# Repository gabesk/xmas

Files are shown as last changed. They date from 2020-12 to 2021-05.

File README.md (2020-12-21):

# xmas
# xmascard
Merry Christmas!

Welcome to the Electronic Christmas Tree Christmas Card. As you no doubt figured out already, to get started just push the button and enjoy the light show.

Additionally, this board is intended to be at least somewhat more than just an amusement; you can do things with it, and the entire schematic and program are open source on GitHub for you to see.

It’s powered by a Lattice FPGA, and you can add new patterns by plugging the USB connector in to the computer.

Unfortunately, I haven't gotten a chance to document this yet; I'll try to do so by Christmas itself. In the meantime, you can poke at the source code and try the instructions below, but I'm not sure they are actually correct. :(

## Interacting with the board

Double click the `light_control.py` file on your computer. It should open a window. Click **Connect**, and follow the instructions. It will ask you to plug in the Christmas Tree board, and if all goes well, it will print that it was successfully connected in the bottom of the window.

Now that you're connected, click any of the lights on the tree. They should change on the board, too! :)

## Creating your own patterns
What else can you do? Well, you can make your own patterns, using the `convert_animation_file.py` and `upload_new_pattern.py` programs.

These programs accept text files containing animations patterns and downloads them to the board for display.

The animation files work like so:

Each step in the animation is specified on a line. Each line specifies the brightness of the LEDs, from the top left to the bottom right. Each LED is two digits from 0 to 7 for the red, then green brightness. The value 0 is off, while 7 is all the way bright. For readability, spaces can be added as desired and are ignored.

For example, to light the red LED on the top, then the entire row of green on the bottom, the line would look like the following:

```
70  00  00 00  00 00 00  07 07 07 07  00
```

Since that can still be hard to read, you can alternately put the LEDs on different lines and separate each step in the animation with a blank line.

This allows you to write the pattern out visually. For example, the above example could also be written as:

```
            70
            00
          00  00
        00  00  00
      07  07  07  07
            00
```

The animation runs at a fixed speed of # frames per second, and the board stores 256 animation steps for a total of # seconds of animation. If you don't use all 256 frames of animation, the program will just repeat the last frame until memory is full.

In order to make it a little easier to create animations, you can tell the program to fade between animation steps automatically.
For example, to create an animation which fades between all the LEDs on, off again, then back on, create a text file like so:

```
set_marker
       77
       77
     77  77
   77  77  77
 77  77  77  77
       77
       77
fade_to
       00
       00
     00  00
   00  00  00
 00  00  00  00
       00
fade_to
       77
       77
     77  77
   77  77  77
 77  77  77  77
       77
       77
repeat_forever
```

Suppose your text file is named animation.txt. First, convert it to an FPGA memory entry like so:
```
convert_animation_file.py animation.txt memory.txt
```
Next, program it to the FPGA like so:
```
upload_new_pattern.py COM3 memory.txt
```
You can find the correct value to use for COM3 by running the `light_control.py` and looking at the value in the box at the bottom of the program after clicking **Connect**.
If everything went well, you should see your animation running on the FPGA. If not, well, you can either treat this as an exercise in learning about Python, or email me and I'll help. :)

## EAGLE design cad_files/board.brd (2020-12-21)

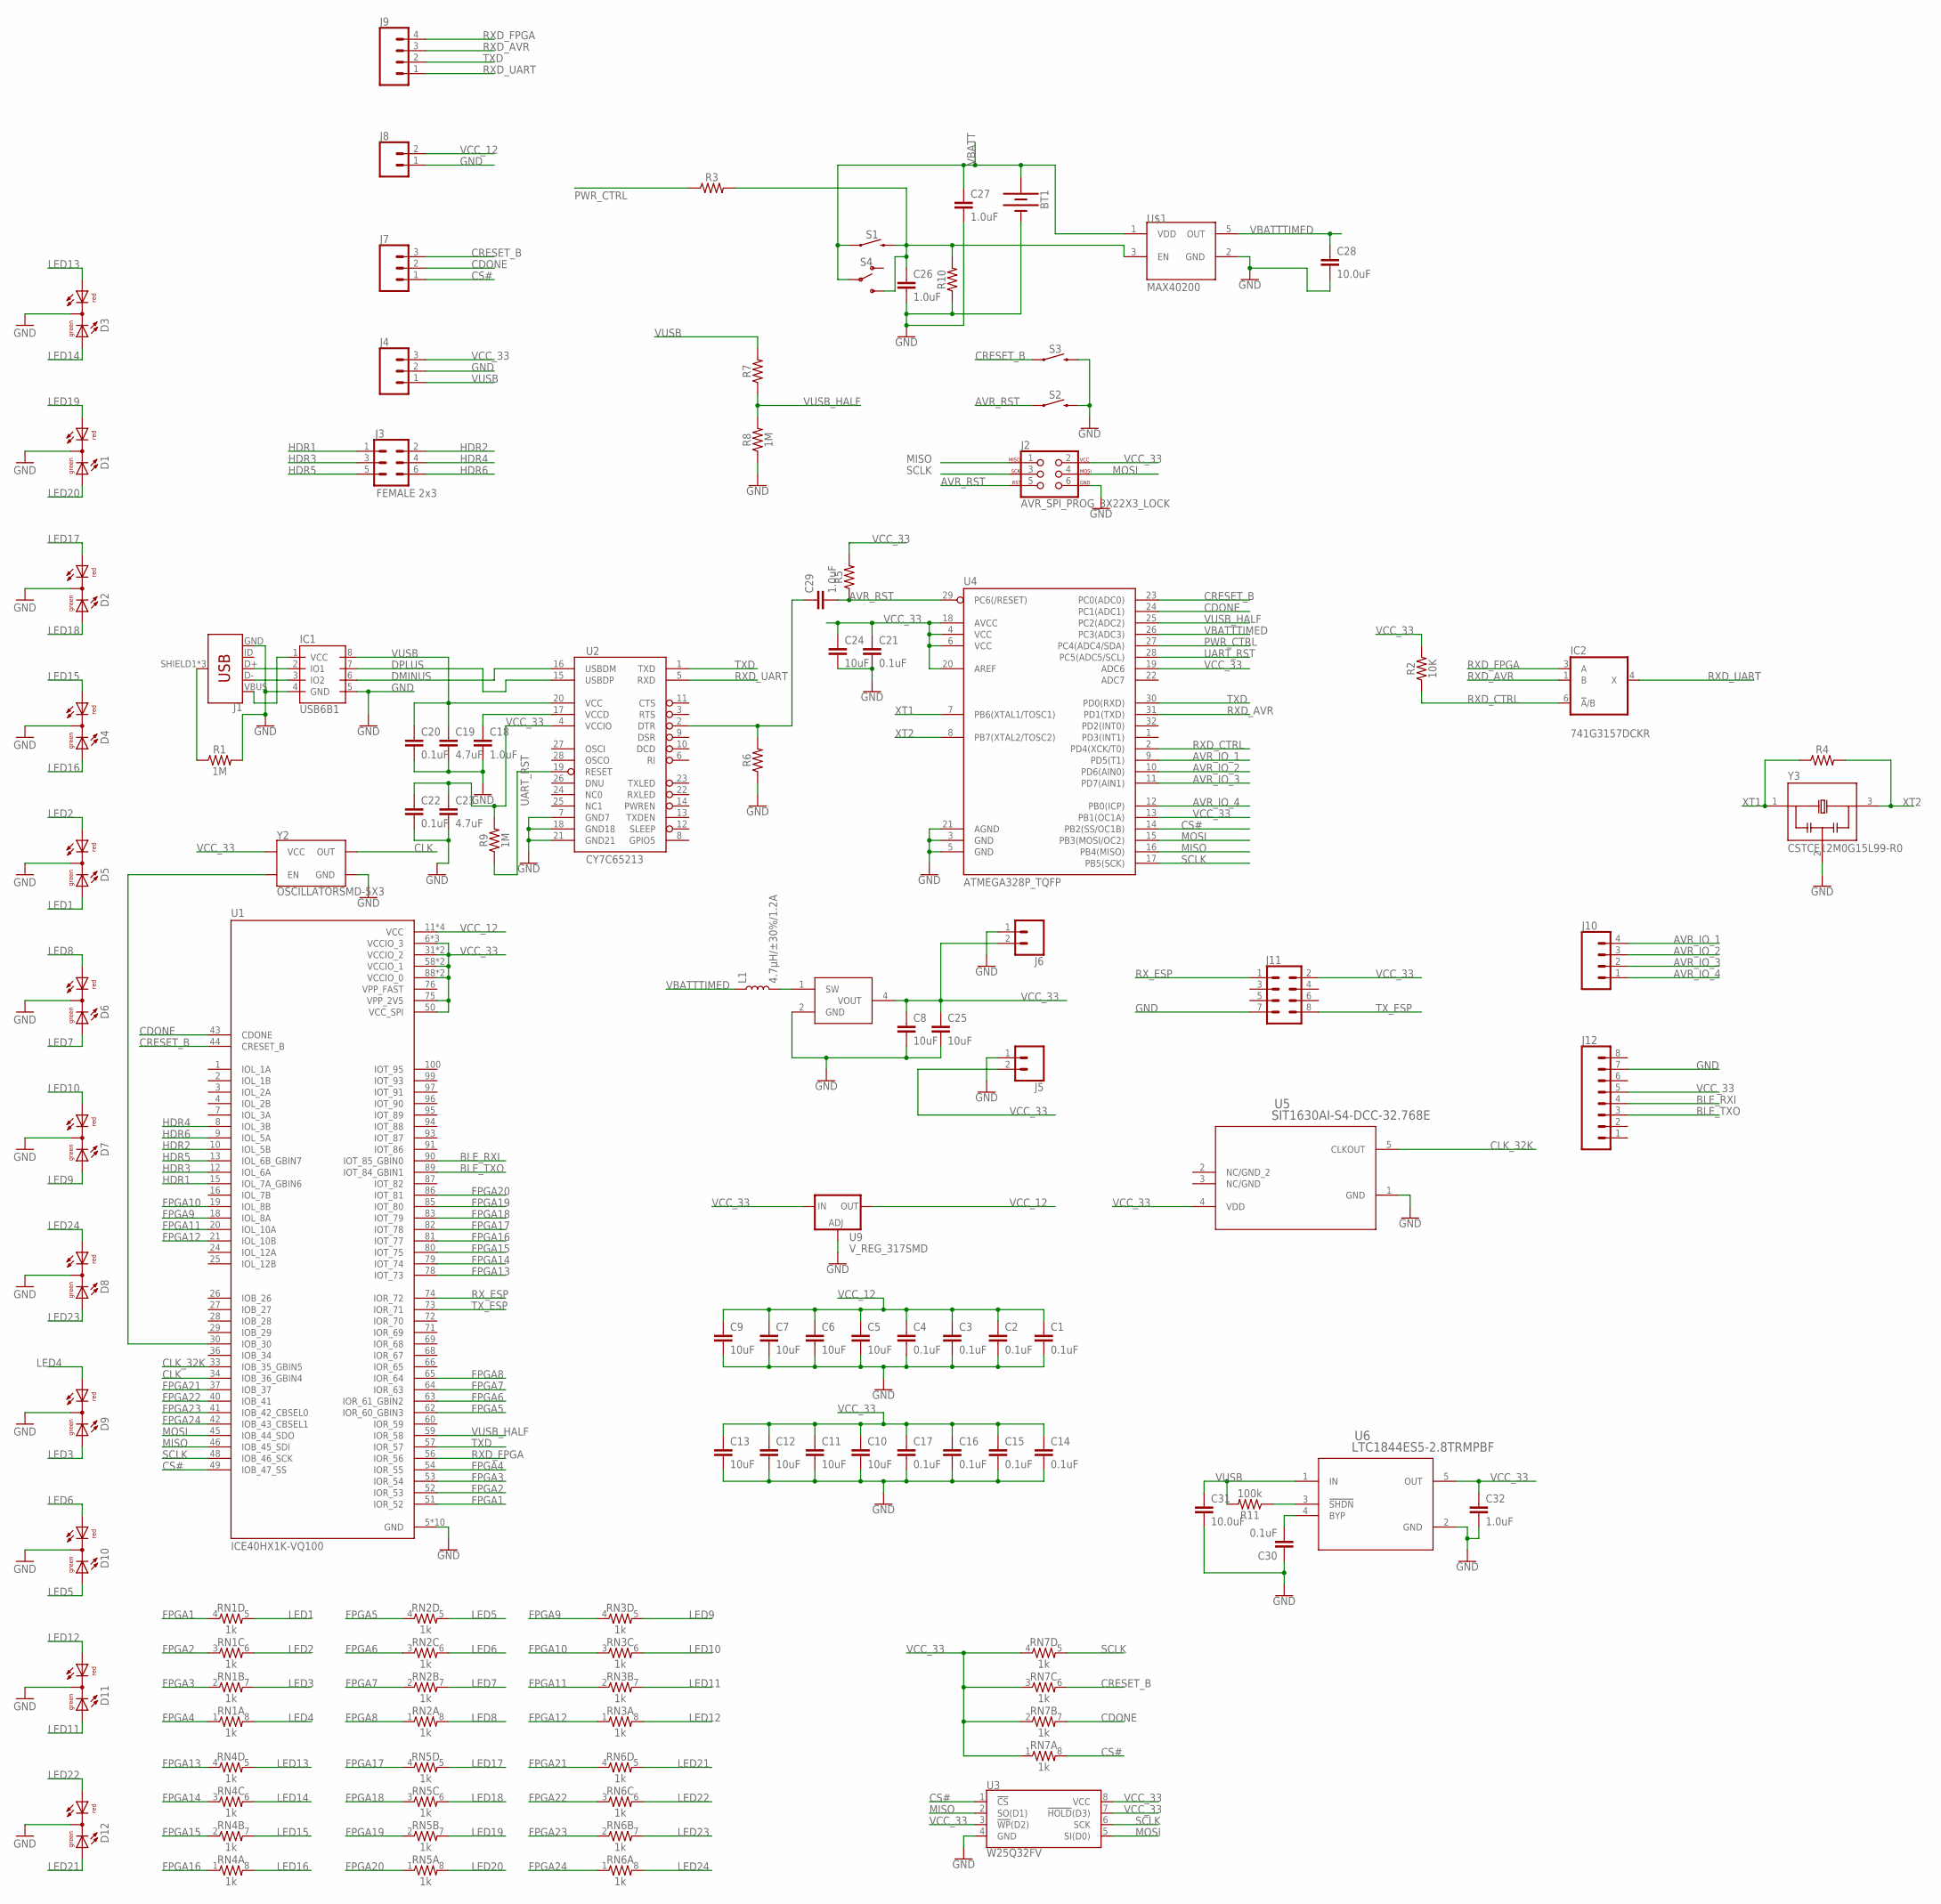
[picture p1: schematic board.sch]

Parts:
BT1: BATTERY-20MM_SMD; BATTCON_20MM
C1, C2, C3, C4, C14, C15, C16, C17, C20, C21, C22, C30: 0.1uF; 0805
C5, C6, C7, C8, C9, C10, C11, C12, C13, C24, C25: 10uF; 0805
C18, C29, C32: 1.0uF; 0805
C19, C23: 4.7uF; 0805
C26, C27: 1.0uF; 0603
C28: 10.0uF; 0603
C31: 10.0uF; 0805
D1, D2, D3, D4, D5, D6, D7, D8, D9, D10, D11, D12: DUOLED5MM
IC1: USB6B1; SO08
IC2: 741G3157DCKR; DCK_R-PDSO-G6
J1: USB_MICRO-B_FEMALE-SMT; USB-B-MICRO-SMD
J2: AVR_SPI_PROG_3X22X3_LOCK; 2X3_LOCK
J3: FEMALE 2x3; 2X3
J4, J7: CONN_03LOCK; 1X03_LOCK
J5, J6, J8: CONN_02LOCK; 1X02_LOCK
J9, J10: CONN_04LOCK; 1X04_LOCK
J11: CONN_04X2; 2X4
J12: CONN_08LOCK; 1X08_LOCK
L1: 4.7µH/±30%/1.2A; INDUCTOR_4.7UH
R1, R8, R9: 1M; 0805
R2: 10K; 0805
R3, R4, R5, R6, R7, R10: 0805
R11: 100k; 0805
RN1, RN2, RN3, RN4, RN5, RN6, RN7: 1k; 0805-ARV
S1, S2, S3: MOMENTARY-SWITCH-SPST-SMD-5.2MM; TACTILE_SWITCH_SMD_5.2MM
S4: SWITCH-SPDT-PTH-11.6X4.0MM; SWITCH_SPDT_PTH_11.6X4.0MM
U1: ICE40HX1K-VQ100; QFP50P1600X1600X120-100N
U2: CY7C65213; SSOP28DB
U3: W25Q32FV; SOIC-8
U4: ATMEGA328P_TQFP; TQFP32-08
U5: SIT1630AI-S4-DCC-32.768E; SOT_SIT1630-S_SIT
U6: LTC1844ES5-2.8TRMPBF; S_5_ADI
U9: V_REG_317SMD; SOT223
U$1: MAX40200; SOT95P280X145-5N
U$2: TPS613221A; SOT95P280X145-5N
Y2: OSCILLATORSMD-5X3; OSCILLATOR-SMD-5X3.2
Y3: CSTCE12M0G15L99-R0; OSC_CSTCE12M0G15L99-R0

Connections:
AVR_IO_1: J10.4, U4.9 (PD5(T1))
AVR_IO_2: J10.3, U4.10 (PD6(AIN0))
AVR_IO_3: J10.2, U4.11 (PD7(AIN1))
AVR_IO_4: J10.1, U4.12 (PB0(ICP))
AVR_RST: C29.2, J2.5, R5.1, S2.1, U4.29 (PC6(/RESET))
BLE_RXI: J12.4, U1.90 (IOT_85_GBIN0)
BLE_TXO: J12.3, U1.89 (IOT_84_GBIN1)
CDONE: J7.2, RN7.7 (2), U1.43 (CDONE), U4.24 (PC1(ADC1))
CLK: U1.34 (IOB_36_GBIN4), Y2.3 (OUT)
CLK_32K: U1.33 (IOB_35_GBIN5), U5.5 (CLKOUT)
CLK_EN: U1.30 (IOB_30), Y2.1 (EN)
CRESET_B: J7.3, RN7.6 (2), S3.1, U1.44 (CRESET_B), U4.23 (PC0(ADC0))
CS#: J7.1, RN7.8 (2), U1.49 (IOB_47_SS), U3.1 (!CS!), U4.14 (PB2(SS/OC1B))
DMINUS: IC1.6 (IO2), U2.16 (USBDM)
DPLUS: IC1.7 (IO1), U2.15 (USBDP)
FPGA1: RN1.4 (1), U1.51 (IOR_52)
FPGA2: RN1.3 (1), U1.52 (IOR_53)
FPGA3: RN1.2 (1), U1.53 (IOR_54)
FPGA4: RN1.1, U1.54 (IOR_55)
FPGA5: RN2.4 (1), U1.62 (IOR_60_GBIN3)
FPGA6: RN2.3 (1), U1.63 (IOR_61_GBIN2)
FPGA7: RN2.2 (1), U1.64 (IOR_63)
FPGA8: RN2.1, U1.65 (IOR_64)
FPGA9: RN3.4 (1), U1.18 (IOL_8A)
FPGA10: RN3.3 (1), U1.19 (IOL_8B)
FPGA11: RN3.2 (1), U1.20 (IOL_10A)
FPGA12: RN3.1, U1.21 (IOL_10B)
FPGA13: RN4.4 (1), U1.78 (IOT_73)
FPGA14: RN4.3 (1), U1.79 (IOT_74)
FPGA15: RN4.2 (1), U1.80 (IOT_75)
FPGA16: RN4.1, U1.81 (IOT_77)
FPGA17: RN5.4 (1), U1.82 (IOT_78)
FPGA18: RN5.3 (1), U1.83 (IOT_79)
FPGA19: RN5.2 (1), U1.85 (IOT_80)
FPGA20: RN5.1, U1.86 (IOT_81)
FPGA21: RN6.4 (1), U1.37 (IOB_37)
FPGA22: RN6.3 (1), U1.40 (IOB_41)
FPGA23: RN6.2 (1), U1.41 (IOB_42_CBSEL0)
FPGA24: RN6.1, U1.42 (IOB_43_CBSEL1)
GND: BT1.2 (-), C1.2, C2.2, C3.2, C4.2, C5.2, C6.2, C7.2, C8.2, C9.2, C10.2, C11.2, C12.2, C13.2, C14.2, C15.2, C16.2, C17.2, C18.2, C19.2, C20.2, C21.2, C22.2, C23.2, C24.2, C25.2, C26.2, C27.2, C28.2, C30.1, C31.2, C32.2, D1.K (C), D2.K (C), D3.K (C), D4.K (C), D5.K (C), D6.K (C), D7.K (C), D8.K (C), D9.K (C), D10.K (C), D11.K (C), D12.K (C), IC1.4 (GND), IC1.5 (GND), IC2.2 (GND), J1.GND, J2.6, J4.2, J5.1, J6.1, J8.1, J11.7, J12.7, R1.2, R6.1, R8.1, R10.1, S2.3 (2), S3.3 (2), U1.5 (GND), U1.17 (GND), U1.23 (GND), U1.32 (GND), U1.39 (GND), U1.47 (GND), U1.55 (GND), U1.70 (GND), U1.84 (GND), U1.98 (GND), U2.7 (GND7), U2.18 (GND18), U2.21 (GND21), U3.4 (GND), U4.3 (GND), U4.5 (GND), U4.21 (AGND), U5.1 (GND), U6.2 (GND), U9.1 (ADJ), U$1.2 (GND), U$2.2 (GND), Y2.2 (GND), Y3.2
HDR1: J3.1, U1.15 (IOL_7A_GBIN6)
HDR2: J3.2, U1.10 (IOL_5B)
HDR3: J3.3, U1.12 (IOL_6A)
HDR4: J3.4, U1.8 (IOL_3B)
HDR5: J3.5, U1.13 (IOL_6B_GBIN7)
HDR6: J3.6, U1.9 (IOL_5A)
LED1: D5.AG, RN1.5 (2)
LED2: D5.AR, RN1.6 (2)
LED3: D9.AG, RN1.7 (2)
LED4: D9.AR, RN1.8 (2)
LED5: D10.AG, RN2.5 (2)
LED6: D10.AR, RN2.6 (2)
LED7: D6.AG, RN2.7 (2)
LED8: D6.AR, RN2.8 (2)
LED9: D7.AG, RN3.5 (2)
LED10: D7.AR, RN3.6 (2)
LED11: D11.AG, RN3.7 (2)
LED12: D11.AR, RN3.8 (2)
LED13: D3.AR, RN4.5 (2)
LED14: D3.AG, RN4.6 (2)
LED15: D4.AR, RN4.7 (2)
LED16: D4.AG, RN4.8 (2)
LED17: D2.AR, RN5.5 (2)
LED18: D2.AG, RN5.6 (2)
LED19: D1.AR, RN5.7 (2)
LED20: D1.AG, RN5.8 (2)
LED21: D12.AG, RN6.5 (2)
LED22: D12.AR, RN6.6 (2)
LED23: D8.AG, RN6.7 (2)
LED24: D8.AR, RN6.8 (2)
MISO: J2.1, U1.46 (IOB_45_SDI), U3.2 (SO(D1)), U4.16 (PB4(MISO))
MOSI: J2.4, U1.45 (IOB_44_SDO), U3.5 (SI(D0)), U4.15 (PB3(MOSI/OC2))
unnamed: C29.1, R6.2, U2.2 (DTR)
unnamed: C18.1, U2.17 (VCCD)
unnamed: J1.SHIELD1 (SHIELD), J1.SHIELD2 (SHIELD), J1.SHIELD3 (SHIELD), R1.1
unnamed: C26.1, R3.2, R10.2, S1.3 (2), S4.3 (S), U$1.3 (EN)
unnamed: C30.2, U6.4 (BYP)
unnamed: R11.1, U6.3 (!SHDN)
unnamed: IC1.2 (IO1), J1.D+
unnamed: IC1.3 (IO2), J1.D-
unnamed: L1.P$2 (2), U$2.1 (SW)
unnamed: IC1.1 (VCC), J1.VBUS
NC1: U2.25 (NC1)
PWR_CTRL: R3.1, U4.27 (PC4(ADC4/SDA))
RXD_AVR: IC2.1 (B), J9.3, U4.31 (PD1(TXD))
RXD_CTRL: IC2.6 (!A!/B), R2.1, U4.2 (PD4(XCK/T0))
RXD_FPGA: IC2.3 (A), J9.4, U1.56 (IOR_56)
RXD_UART: IC2.4 (X), J9.1, U2.5 (RXD)
RX_ESP: J11.1, U1.74 (IOR_72)
SCLK: J2.3, RN7.5 (2), U1.48 (IOB_46_SCK), U3.6 (SCK), U4.17 (PB5(SCK))
TXD: J9.2, U1.57 (IOR_57), U2.1 (TXD), U4.30 (PD0(RXD))
TX_ESP: J11.8, U1.73 (IOR_71)
UART_RST: R9.1, U2.19 (RESET), U4.28 (PC5(ADC5/SCL))
VBATT: BT1.1 (+), C27.1, S1.1, S4.2, U$1.1 (VDD)
VBATTTIMED: C28.1, L1.P$1 (1), U4.26 (PC3(ADC3)), U$1.5 (OUT)
VCC_12: C1.1, C2.1, C3.1, C4.1, C5.1, C6.1, C7.1, C9.1, J8.2, U1.11 (VCC), U1.35 (VCC), U1.61 (VCC), U1.77 (VCC), U9.2 (OUT)
VCC_33: C8.1, C10.1, C11.1, C12.1, C13.1, C14.1, C15.1, C16.1, C17.1, C21.1, C22.1, C23.1, C24.1, C25.1, C32.1, IC2.5 (VCC), J2.2, J4.3, J5.2, J6.2, J11.2, J12.5, R2.2, R5.2, R9.2, RN7.1, RN7.2 (1), RN7.3 (1), RN7.4 (1), U1.6 (VCCIO_3), U1.14 (VCCIO_3), U1.22 (VCCIO_3), U1.31 (VCCIO_2), U1.38 (VCCIO_2), U1.50 (VCC_SPI), U1.58 (VCCIO_1), U1.67 (VCCIO_1), U1.75 (VPP_2V5), U1.88 (VCCIO_0), U1.92 (VCCIO_0), U2.4 (VCCIO), U3.3 (!WP!(D2)), U3.7 (!HOLD!(D3)), U3.8 (VCC), U4.4 (VCC), U4.6 (VCC), U4.13 (PB1(OC1A)), U4.18 (AVCC), U4.19 (ADC6), U4.20 (AREF), U5.4 (VDD), U6.5 (OUT), U9.3 (IN), U$2.4 (VOUT), Y2.4 (VCC)
VPP_FAST: U1.76 (VPP_FAST)
VUSB: C19.1, C20.1, C31.1, IC1.8 (VCC), J4.1, R7.2, R11.2, U2.20 (VCC), U6.1 (IN)
VUSB_HALF: R7.1, R8.2, U1.59 (IOR_58), U4.25 (PC2(ADC2))
XT1: R4.1, U4.7 (PB6(XTAL1/TOSC1)), Y3.1
XT2: R4.2, U4.8 (PB7(XTAL2/TOSC2)), Y3.3

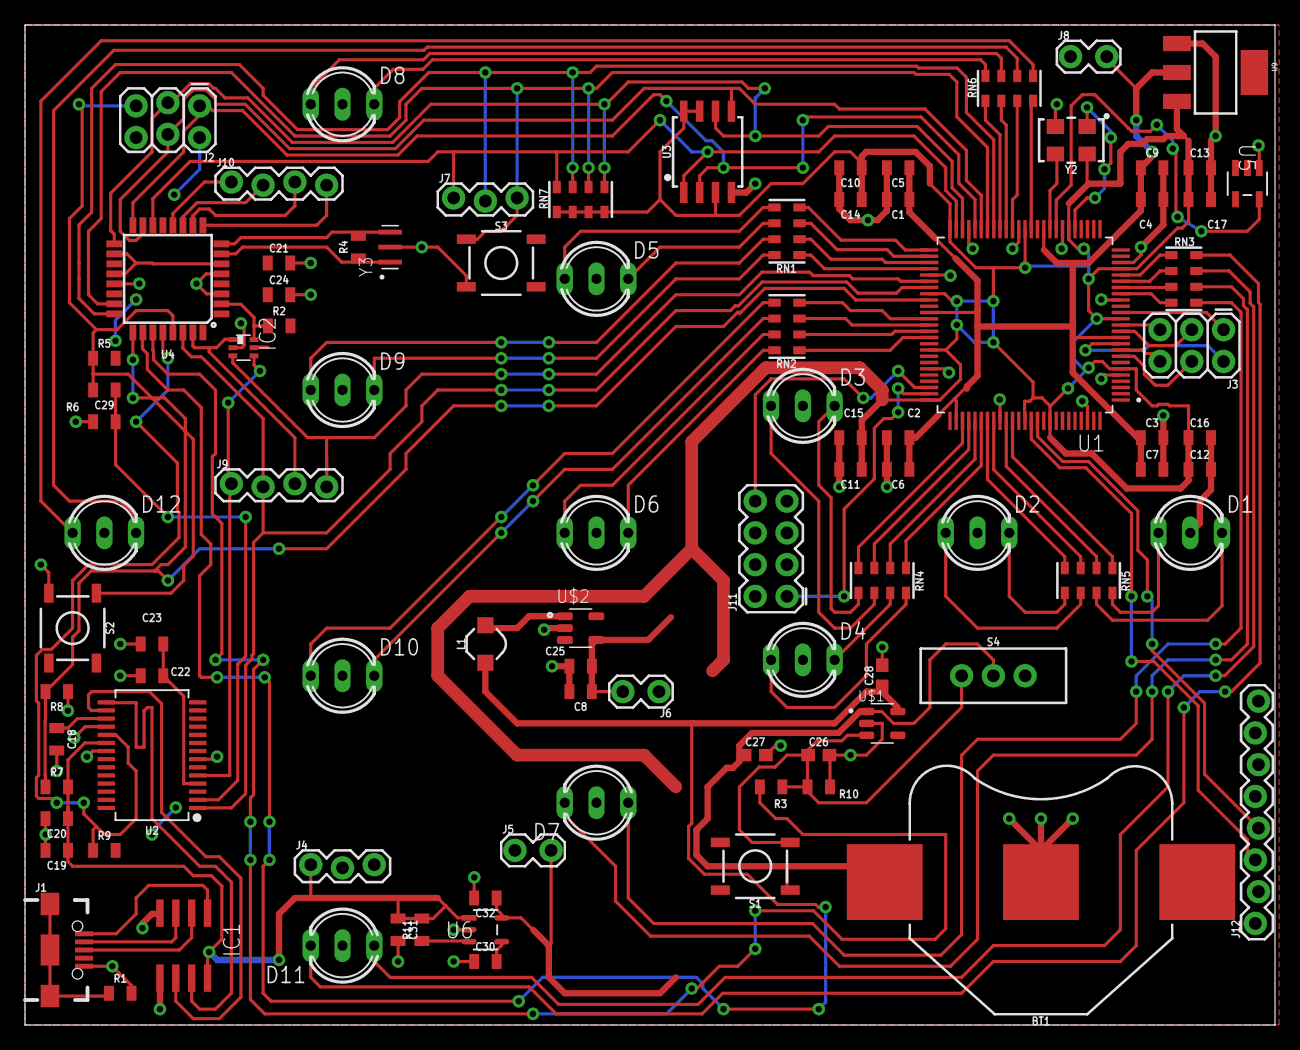
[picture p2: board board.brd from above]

Board: 2 copper layers, 100.0 x 80.0 mm, 93 parts (0 on the bottom side), 100 nets.

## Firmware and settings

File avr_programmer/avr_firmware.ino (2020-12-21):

//#define F_CPU 8000000
//#define BAUD 38400
#define F_CPU 7370000
#define BAUD 115200
#define NULL 0

#include <avr/io.h>
#include <avr/interrupt.h>
#include <avr/sleep.h>
#include <avr/wdt.h>
#include <util/delay.h>
#include <util/setbaud.h>

#define DDR_SPI DDRB
#define PORT_SPI PORTB
#define PIN_SS PORTB2
#define PIN_MISO PORTB4
#define DD_MISO DDB4
#define DD_MOSI DDB3
#define DD_SCK DDB5
#define DD_SS DDB2

// See SetupFpgaResetAndDone for more notes
#define DDR_CRESET DDRC
#define DDR_CDONE DDRC
#define DDR_VBATT DDRC
#define DDR_UART_RST DDRC
#define DDR_PWR_CTRL DDRC
#define DDR_RXD_CTRL DDRD


#define PORT_CRESET PORTC
#define PORT_CDONE PORTC
#define PORT_VBATT PORTC
#define PORT_UART_RST PORTC
#define PORT_PWR_CTRL PORTC
#define PORT_RXD_CTRL PORTD


#define PIN_CRESET PINC
#define PIN_CDONE PINC
#define PIN_VBATT PINC
#define PIN_UART_RST PINC
#define PIN_PWR_CTRL PINC
#define PIN_RXD_CTRL PIND


#define BIT_CRESET PINC0
#define BIT_CDONE PINC1
#define BIT_VBATT PINC3
#define BIT_UART_RST PINC5
#define BIT_PWR_CTRL PORTC4
#define BIT_RXD_CTRL PORTD4

void USART_Init( void );
void USART_Transmit( unsigned char data );
unsigned char USART_Receive_With_Error( unsigned char* frame_error );
unsigned char USART_Receive( void );
void USART_Flush( void );

void SPI_MasterInit(void);
void SPI_MasterTransmit(char cData);
void SPI_MasterTransmit_WaitBefore(char cData);
char SPI_SlaveReceive(void);

void ReleaseSpiFlashFromPowerDown(void);

void SetupFpgaResetAndDone();
void PutFpgaIntoReset();
void PutFpgaOutOfReset();
unsigned char ReadFpgaDoneBit();

int ReadBatteryVoltage();
int ReadUsbVoltage();

void TurnOffCard();

char pageodata[260];
int pageaddress;

volatile int watchdogs_until_sleep = 20;

// watchdog interrupt
ISR (WDT_vect) 
{
  watchdogs_until_sleep--;
  // wdt_disable();  // disable watchdog
}  // end of WDT_vect

void setup() {
  SPI_MasterInit();
  SetupFpgaResetAndDone();
  
  PRR &= ~(1<<PRADC);
}

void loop() {

  unsigned char err;
  unsigned char cmd;
  unsigned char initial_cmd;

  PORTD |= (1 << 5);
  
  cmd = '?';
  initial_cmd = 0;
  
  USART_Init();

  {
    int initialUsbVoltage = ReadUsbVoltage();
    if (initialUsbVoltage < 700) {
      noInterrupts();

      // disable ADC 
      ADCSRA = 0;

      // Disable SPI
      SPCR &= ~(1<<SPE);

      // Disable USART
      UCSR0B &= (~(1<<RXEN0)) & (~(1<<TXEN0));

      // Tri-state all the I/O
      // (temporarily disable pullups to avoid temporiarily sinking current if the pin was previously an output high)
      MCUCR &= ~(1<<PUD);

      // Then set everything to tri-state.
      PORTB = DDRB = PORTC = DDRC = PORTD = DDRD = 0;

      // but not the pwr ctrl pin otherwise the board won't stay on :)
      DDR_PWR_CTRL |=  (1 << BIT_PWR_CTRL);
      PORT_PWR_CTRL |=  (1 << BIT_PWR_CTRL);

      // And re-enable the pull ups so that all pins have a defined state when entering sleep.
      //MCUCR |= (1<<PUD);

      // clear various "reset" flags
      MCUSR = 0;     
      // allow changes, disable reset
      WDTCSR = bit (WDCE) | bit (WDE);
      // set interrupt mode and an interval 
      WDTCSR = bit (WDIE) | bit (WDP2) | bit (WDP1);    // set WDIE, and 1 second delay
      //WDTCSR = bit (WDIE) | bit (WDP3) | bit (WDP0);      // set WDIE, and 8 second delay
      wdt_reset();  // pat the dog
  
      while (watchdogs_until_sleep) {
        set_sleep_mode (SLEEP_MODE_PWR_DOWN);  
        noInterrupts ();           // timed sequence follows
        sleep_enable();
       
        // turn off brown-out enable in software
        MCUCR = bit (BODS) | bit (BODSE);  // turn on brown-out enable select
        MCUCR = bit (BODS);        // this must be done within 4 clock cycles of above
  
        interrupts ();             // guarantees next instruction executed
        sleep_cpu ();              // sleep within 3 clock cycles of above
        sleep_disable();
      }

      TurnOffCard();
      while(1);
    }
  }

  do {
    //USART_Transmit(b);
    /* generate a clock on user io */
    if (cmd == 'j') {
      DDRD |= (1 << 5);
      while (1) {
        PORTD &= ~(1 << 5);
        PORTD &= ~(1 << 5);
        PORTD |= (1 << 5);
      }      
    }
    
    /* Configure SS as low (enabled) */
    if (cmd == 'l') {
      PORT_SPI &= ~(1<<PIN_SS);
        
      //USART_Transmit('l');
        
    }
    
    /* Configure SS as high (disabled) */
    else if (cmd == 'r') {
      PORT_SPI |= (1<<PIN_SS);
        
      //USART_Transmit('r');
        
    }
    
    /* Send/receive a byte (transaction) over the SPI connection */
    else if (cmd == 'b') {
      //USART_Transmit('b');
        
      unsigned char to_slave = USART_Receive();
      SPI_MasterTransmit(to_slave);
        
      unsigned char from_slave = SPI_SlaveReceive();
      USART_Transmit(from_slave);
        
    }
    
    /* Program a page of data */
    else if (cmd == 'p') {
      // Receive 256 + 3 address + 1 command byte
      for (int i=0;i<260;i++) {
        pageodata[i] = USART_Receive();
      }
        
      USART_Transmit('a');
        
      PORT_SPI &= ~(1<<PIN_SS);
      for (int i=0;i<260;i++) {
        SPI_MasterTransmit(pageodata[i]);
      }
      PORT_SPI |= (1<<PIN_SS);
        
      USART_Transmit('d');
        
    } 
    
    /* Verify a page of data */
    else if (cmd == 'v') {
      // Read 1 command byte and 3 address bytes
      // (just store it in the page array for now since it won't be needed once transmitted to the spi flash)
      for (int i=0;i<4;i++) {
        pageodata[i] = USART_Receive();
      }
        
      PORT_SPI &= ~(1<<PIN_SS);
        
      // Transmit cmd + addr
      for (int i=0;i<4;i++) {
        SPI_MasterTransmit(pageodata[i]);
      }

      // Read back 256 bytes of page memory
      for (int i=0;i<256;i++) {
        SPI_MasterTransmit(0);
        pageodata[i] = SPI_SlaveReceive();
      }
        
      PORT_SPI |= (1<<PIN_SS);
        
      // Transmit it back over serial
      for (int i=0;i<256;i++) {
        USART_Transmit(pageodata[i]);
      }
        
      /* Unknown command */
    }

    else if (cmd == 'f') {
      // Fast program. Overlap sending the spi bytes with the receive bytes.
      // Receive a byte, send it to spi, the immediately receive another byte from serial knowing that the SPI will
      // finish by the time the next one is done.
      PORT_SPI &= ~(1<<PIN_SS);
      SPDR = USART_Receive();
      for (int i=0;i<259;i++) {
        SPI_MasterTransmit_WaitBefore(USART_Receive());
      }
      while(!(SPSR & (1<<SPIF)));
      PORT_SPI |= (1<<PIN_SS);
      USART_Transmit('a');
      USART_Transmit('d');
    }
      
    else if (cmd == 'g') {
      // Fast verify.
      PORT_SPI &= ~(1<<PIN_SS);
      SPDR = USART_Receive();  // receive a byte, start is sending, immediately go back to receiving a new byte
      for (int i=0;i<3;i++) {
        SPI_MasterTransmit_WaitBefore(USART_Receive());
      }

      // since using WaitBefore, old byte still sending, so wait for it to finish
      while(!(SPSR & (1<<SPIF)));
        
      SPI_MasterTransmit(0);    // get byte 0 of page data into SPDR0
      for (int i=0;i<255;i++) {
        char incoming_byte = SPI_SlaveReceive();
        SPDR = 0;        // unless it's the last byte, start a new transmission
        USART_Transmit(incoming_byte);  // transmit old received byte (starting with byte 0 and ending with byte 254)
      }
      USART_Transmit(SPDR);    // transmit byte 255 but don't start a new transmission
      while(!(SPSR & (1<<SPIF)));
      PORT_SPI |= (1<<PIN_SS);
    }
      
    else if (cmd == 'q') {
      PutFpgaIntoReset();
      USART_Transmit('q');
    }
      
    else if (cmd == 'w') {
      PutFpgaOutOfReset();
      USART_Transmit('w');
    }
      
    else if (cmd == 'e') {
      USART_Transmit(ReadFpgaDoneBit());
    }
      
    else if (cmd == 't') {
      ReleaseSpiFlashFromPowerDown();
      USART_Transmit('t');
    }
      
    else if (cmd == 'z') {
      if (!initial_cmd) {
        USART_Transmit('z');
        USART_Flush();
        // Delay a bit to give this character a chance to end properly before switching over to whatever junk the FPGA is sending.
        _delay_ms(100);
      }
      PORT_RXD_CTRL &= ~(1 << BIT_RXD_CTRL);
      while (1) {
          
        // Provide a way to regain control from FPGA passthrough.
        // If a break symbol is transmitted (which is just the serial
        // line going low for much longer than a single byte,
        // introducing a framing error), break out of the passthrough
        // loop and regain control.
        unsigned char dummy = USART_Receive_With_Error(&err);
        if (err) {
          PORT_RXD_CTRL |= (1 << BIT_RXD_CTRL);
          break;
        }
      }
    }
    
    else if (cmd == 'c') {
      USART_Transmit('c');
      int value = ReadBatteryVoltage();
      for (int idx=0;idx<4;idx++) {
        int nibble = ((value & 0xF000) >> 12) + 48;
        if (nibble > 57) nibble += 7;
        value = value << 4;
        USART_Transmit(nibble);
      }
    }
    
    else if (cmd == 'u') {
      USART_Transmit('u');
      int value = ReadUsbVoltage();
      for (int idx=0;idx<4;idx++) {
        int nibble = ((value & 0xF000) >> 12) + 48;
        if (nibble > 57) nibble += 7;
        value = value << 4;
        USART_Transmit(nibble);
      }
    }
    
    else if (cmd == 'y') {
      USART_Transmit('y');
      unsigned int value = 0xabcd;
      for (int idx=0;idx<4;idx++) {
        int nibble = ((value & 0xF000) >> 12) + 48;
        if (nibble > 57) nibble += 7;
        value = value << 4;
        USART_Transmit(nibble);
      }     
      USART_Transmit('d');
    }

    else if (cmd == 's') {
      USART_Transmit('s');
      noInterrupts();
      
      // disable ADC
      ADCSRA = 0;
      
      set_sleep_mode (SLEEP_MODE_PWR_DOWN);  
      noInterrupts ();           // timed sequence follows
      sleep_enable();
     
      // turn off brown-out enable in software
      MCUCR = bit (BODS) | bit (BODSE);  // turn on brown-out enable select
      MCUCR = bit (BODS);        // this must be done within 4 clock cycles of above
      interrupts ();             // guarantees next instruction executed
      sleep_cpu ();              // sleep within 3 clock cycles of above
    }
    
    else {
      USART_Transmit('?');
    }
    
    cmd = USART_Receive();
    initial_cmd = 0;
  } while (1);
}

void USART_Init( void )
{
  /*Set baud rate */
  UBRR0H = UBRRH_VALUE;
  UBRR0L = UBRRL_VALUE;

  /* Enable receiver and transmitter */
  UCSR0B = (1<<RXEN0)|(1<<TXEN0);

  /* Set frame format: 8data, 1stop bit */
  UCSR0C = (3<<UCSZ00);
}
void USART_Transmit( unsigned char data )
{
  /* Wait for empty transmit buffer */
  while ( !( UCSR0A & (1<<UDRE0)))
    ;

  /* Put data into buffer, sends the data */
  UDR0 = data;
}

unsigned char USART_Receive()
{
  return USART_Receive_With_Error(NULL);
}

unsigned char USART_Receive_With_Error( unsigned char* frame_error )
{
  unsigned char status, resh, resl;
  
  /* Wait for data to be received */
  while ( !(UCSR0A & (1<<RXC0)) )
    ;
  
  /* Get status, then data from buffer */
  status = UCSR0A;
  resh = UCSR0B;
  resl = UDR0;
  
  /* Indicate frame errors */
  if (frame_error) {
    *frame_error = 0;
    if ( status & (1<<FE0) ) {
      *frame_error = 1; 
    }
  }
  
  return resl;
}

void USART_Flush( void )
{
  unsigned char dummy;
  while ( UCSR0A & (1<<RXC0) ) dummy = UDR0;
}

void SPI_MasterInit(void)
{
  /* Set MOSI, SS, and SCK output, all others input */
  DDR_SPI = (1<<DD_MOSI)|(1<<DD_SCK)|(1<<DD_SS);
  
  /* Configure MISO as high-z */
  PORT_SPI &= ~(1 << PIN_MISO);
  
  /* Configure SS as high (disabled) */
  PORT_SPI |= (1 << PIN_SS);
  
  /* Enable SPI, Master, set clock rate fck/16 */
  SPCR = (1<<SPE)|(1<<MSTR)|(1<<SPR0);
}

void SPI_MasterTransmit(char cData)
{
  /* Start transmission */
  SPDR = cData;
  
  /* Wait for transmission complete */
  while(!(SPSR & (1<<SPIF)))
  ;
}
void SPI_MasterTransmit_WaitBefore(char cData)
{
  /* Wait for transmission complete */
  while(!(SPSR & (1<<SPIF)))
  ;

  /* Start transmission */
  SPDR = cData;
}
char SPI_SlaveReceive(void)
{
  /* Wait for reception complete */
  while(!(SPSR & (1<<SPIF)))
  ;
  
  /* Return Data Register */
  return SPDR;
}

void ReleaseSpiFlashFromPowerDown(void) {
  PORT_SPI &= ~(1<<PIN_SS);
  SPI_MasterTransmit(0xAB);
  PORT_SPI |= (1<<PIN_SS);
  _delay_us(10);
}




void SetupFpgaResetAndDone() {
  // CRESET#  -> pin 23 -> PC0 (ADC0)
  // CDONE_B  -> pin 24 -> PC1 -> input (ADC1)
  // VBATT    -> pin 26 -> PC3 -> analog input (ADC3)
  // PWR_CTRL -> pin 27 -> PC4 -> output (ADC4)
  // RXD_CTRL -> pin 2  -> PD4 -> output
  //
  // Normally CRESET is open-circuit so it can float high
  // When we want to reset the FPGA, turn it to an input, low, so it pulls the FPGA low
  
  DDR_CRESET   &= ~(1 << BIT_CRESET);
  DDR_CDONE    &= ~(1 << BIT_CDONE);
  DDR_VBATT    &= ~(1 << BIT_VBATT);
  DDR_PWR_CTRL |=  (1 << BIT_PWR_CTRL);
  DDR_RXD_CTRL |=  (1 << BIT_RXD_CTRL);

  PORT_CRESET   &= ~(1 << BIT_CRESET);
  PORT_CDONE    &= ~(1 << BIT_CDONE);
  PORT_VBATT    &= ~(1 << BIT_VBATT);
  PORT_PWR_CTRL |=  (1 << BIT_PWR_CTRL);
  //PORT_PWR_CTRL &= ~(1 << BIT_PWR_CTRL);
  PORT_RXD_CTRL |= (1 << BIT_RXD_CTRL); // i have control
  //PORT_RXD_CTRL &= ~(1 << BIT_RXD_CTRL); // fpga has control

  DDRD |= (1 << 5);
  
  
  ADCSRA = (1 << ADEN); // Enable ADC, let the rest stay at defaults
}

void PutFpgaIntoReset() {
  // Not needed because already set low for Tri-state in initialization
  // PORT_CRESET   &= ~(1 << BIT_CRESET); // Set output low
  DDR_CRESET |= (1 << BIT_CRESET); // Turn pin into output
}

void PutFpgaOutOfReset() {
  DDR_CRESET &= ~(1 << BIT_CRESET); // Turn pin into input
  // Not needed because already set low for Tri-state in initialization
  // PORT_CRESET |= (1 << BIT_CRESET);  // Set output low
}

unsigned char ReadFpgaDoneBit() {
  if (PIN_CDONE & (1 << BIT_CDONE)) return 1;
  else return 0;
}

int ReadBatteryVoltage() {
  
  // Set up the ADC to read the VBATT signal
  ADMUX = 3; // MUX = ADC3

  ADCSRA |= (1 << ADSC); // start conversion
  
  while ( (ADCSRA & (1 << ADSC) ) );
  //while ( (ADCSRA & (1 << ADIF)) == 0 ); // wait for it to finish (interrupt flag set)
  ADCSRA |= (1 << ADIF); // and clear it
  
  int result = ADCL; // read result - low register must be read first
  result |= (ADCH << 8);
  
  //PRR0 |= 1<<PRADC;
  return result;
}

int ReadUsbVoltage() {
  
  // Set up the ADC to read the VUSB_HALF signal
  ADMUX = 2; // MUX = ADC2
  
  ADCSRA |= (1 << ADSC); // start conversion
  
  //while ( (ADCSRA & (1 << ADSC) ) );
  while ( (ADCSRA & (1 << ADIF)) == 0 ); // wait for it to finish (interrupt flag set)
  ADCSRA |= (1 << ADIF); // and clear it
  
  int result = ADCL; // read result - low register must be read first
  result |= (ADCH << 8);
  
  //PRR0 |= 1<<PRADC;
  return result;
}

volatile unsigned char timer_overflow_cnt;

ISR(TIMER1_OVF_vect) {

  static int huh = 0;
  
  if (huh) {
    huh = 0;
    PORTD &= ~(1 << 5);
  }
  else {
    huh = 1;
    PORTD |= (1 << 5);
  }
  
  timer_overflow_cnt++;
  if (timer_overflow_cnt == 18) {
    // Turn off the circuit.
    //PORT_PWR_CTRL &=  ~(1 << BIT_PWR_CTRL);
    // Immediately after writing ^ everything should lose power and nothing else will execute because there will be no more power.
    // Unless the circuit is on USB, in which case it will remain powered by the USB circuity, but at least the battery will stop
    // draining.
  }
}

void TurnOffCard() {
  // Turn off the circuit.
  PORT_PWR_CTRL &=  ~(1 << BIT_PWR_CTRL);
  // Immediately after writing ^ everything should lose power and nothing else will execute because there will be no more power.
  // Unless the circuit is on USB, in which case it will remain powered by the USB circuity, but at least the battery will stop
  // draining.
}

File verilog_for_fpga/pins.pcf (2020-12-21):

# LED
set_io --warn-no-port leds[0] 85
set_io --warn-no-port leds[1] 86
set_io --warn-no-port leds[2] 82
set_io --warn-no-port leds[3] 83
set_io --warn-no-port leds[4] 78
set_io --warn-no-port leds[5] 79
set_io --warn-no-port leds[6] 80
set_io --warn-no-port leds[7] 81
set_io --warn-no-port leds[8] 52
set_io --warn-no-port leds[9] 51
set_io --warn-no-port leds[10] 65
set_io --warn-no-port leds[11] 64
set_io --warn-no-port leds[12] 18
set_io --warn-no-port leds[13] 19
set_io --warn-no-port leds[14] 42
set_io --warn-no-port leds[15] 41
set_io --warn-no-port leds[16] 54
set_io --warn-no-port leds[17] 53
set_io --warn-no-port leds[18] 63
set_io --warn-no-port leds[19] 62
set_io --warn-no-port leds[20] 20
set_io --warn-no-port leds[21] 21
set_io --warn-no-port leds[22] 40
set_io --warn-no-port leds[23] 37

set_io --warn-no-port clk_fast 34

#set_io --warn-no-port clk 13 # this one is the extra pin
#set_io --warn-no-port clk 45 # this is mosi or some shit when i was feeding it from the avr

set_io --warn-no-port clk_slow 33
set_io --warn-no-port clk_fast_en 30

set_io --warn-no-port vusb_half 59

set_io --warn-no-port rx 57
set_io --warn-no-port tx 56

set_io --warn-no-port user_io[0] 15
set_io --warn-no-port user_io[1] 10
set_io --warn-no-port user_io[2] 12
set_io --warn-no-port user_io[3] 8
set_io --warn-no-port user_io[4] 13
set_io --warn-no-port user_io[5] 9

set_io --warn-no-port ble_rxi 90
set_io --warn-no-port ble_txo 89

set_io --warn-no-port esp_rxi 74
set_io --warn-no-port esp_txo 73

set_io --warn-no-port cs_n 49
set_io --warn-no-port sclk 48
set_io --warn-no-port mosi 45
set_io --warn-no-port miso 46

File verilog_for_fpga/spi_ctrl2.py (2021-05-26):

import argparse
import sys
import serial
import struct
import random
import time

parser = argparse.ArgumentParser()
parser.add_argument("com_port", help="The com port of the FPGA (ex: 'COM3:')")
parser.add_argument("prom_file", help="The BIN prom file to program")
args = parser.parse_args()
ser = serial.Serial(args.com_port, 115200, timeout=2)

def write_byte(num):
    byte = struct.pack('B', int(num))
    ser.write(byte)
    #ser.flush()

def lower_cs():
    ser.write(b'l')

def raise_cs():
    ser.write(b'r')

def readwrite_spi_byte(to):
    ser.write(b'b')
    write_byte(to)
    b = ser.read()
    if len(b) != 1:
        # Something unexpected happened. Try to raise chip select to place SPI
        # flash in known state.
        raise_cs()
        raise_cs()
        raise_cs()
        raise_cs()
        raise Exception("Timeout reading data from COM port.")

    return b

def transact(cmd, bytes_to, num_bytes_back):
    lower_cs()
    readwrite_spi_byte(cmd)
    for b in bytes_to:
        readwrite_spi_byte(b)
    bytes_back = []
    for i in range(num_bytes_back):
        bytes_back.append(readwrite_spi_byte(0))
    raise_cs()
    
    return b''.join(bytes_back)

def validate_id():
    id = transact(0x9f, b'', 3)
    if id != bytes.fromhex('c22012'):
        raise Exception("ID from chip doesn't match. Expected 0xc22013 but got 0x%s." % (id.hex()))
        pass
    return id

def make_three_byte_address(addr):
    # Note the > in struct.pack because this address must be big endian as it is
    # sent to flash LSB first.
    addr_bytes = struct.pack('>I', addr)
    if (addr_bytes[0] != 0):
        raise Exception("Invalid address: 0x%x." % (addr))
    return addr_bytes[1:]
    
def read_page(addr):
    data = transact(0x03, make_three_byte_address(addr), 256)
    #print(repr(data))
    return data

def read_status(write_enable_set, write_in_progress_set = False, raise_if_not = True):
    status = transact(0x05, b'', 1)
    status = struct.unpack('B', status)[0]
    #print('Read status of 0x%x' % (status))
    write_enable_status = status & 2 != 0
    write_in_progress_status = status & 1 != 0
    if write_enable_set != write_enable_status or write_in_progress_set != write_in_progress_status:
        if raise_if_not:
            raise Exception("Status byte not as expected: 0x%x. write_enable_set:%s write_in_progress_set:%s" % (status, write_enable_set, write_in_progress_set))
        return False
    return True

def assert_page_is_blank(addr):
    d = read_page(addr)
    blank = d == b'\xff'*256
    if not blank:
        print(repr(d))
        raise Exception("Page 0x%x isn't blank." % (addr))

def enable_write():
    transact(0x06, b'', 0)
    read_status(write_enable_set = True)

def disable_write():
    transact(0x04, b'', 0)
    status = read_status(write_enable_set = False)

def wait_for_write_complete():
    status_reads = 0
    while read_status(write_enable_set = True, write_in_progress_set = True, raise_if_not = False) == True:
        #print('wait_for_write_complete ...')
        status_reads += 1

    read_status(write_enable_set = False)
    #print('Write complete after %d status reads.' % (status_reads))
    
def erase_sector(addr):
    # TODO: Check if sector is blank first

    enable_write()

    transact(0x20, make_three_byte_address(addr), 0)

    wait_for_write_complete()

def read_page_fast(addr):
    toser = b'g' + struct.pack('B', 0x03) + make_three_byte_address(addr)
    ser.write(toser)
    b = ser.read(256)
    #print(len(b))
    assert len(b) == 256
    return b
    
def program_page(addr, data):
    #assert_page_is_blank(addr)

    enable_write()

    #print(len(make_three_byte_address(addr) + data))
    
    #transact(0x02, make_three_byte_address(addr) + data, 0)
    toser = b'f' + struct.pack('B', 0x02) + make_three_byte_address(addr) + data
    #print('will send this much data:')
    #print(len(toser))
    #print('and it is')
    #print(repr(toser))
    
    ser.write(toser)
    b = ser.read()
    #print(repr(b))
    assert b == b'a'

    b = ser.read()
    #print(repr(b))
    assert b == b'd'

    #wait_for_write_complete()

def test():
    random_page_of_data = b''
    for i in range(256):
        random_page_of_data += struct.pack('B', random.randint(0,255))
    
    print('Erasing sector')
    erase_sector(0x07F000)
    print('Done')
    
    print('Am going to program this:')
    print(repr(random_page_of_data))
    print(len(random_page_of_data))
    program_page(0x07F000, random_page_of_data)
    print('Done. Now reading it back.')
    data_back = read_page(0x07F000)
    print('Got back:')
    print(repr(data_back))
    print(random_page_of_data == data_back)

def put_fpga_into_reset():
    ser.write(b'q')
    b = ser.read()
    #print(repr(b))
    assert b == b'q'

def put_fpga_out_of_reset():
    ser.write(b'w')
    b = ser.read()
    assert b == b'w'

def wait_for_fpga_done():
    status_reads = 0
    b = b'\x00'

    while b == b'\x00':
        if status_reads > 40:
            raise Exception('FPGA not done after %s status reads.' % (status_reads))

        status_reads += 1
        ser.write(b'e')
        b = ser.read()

    assert b == b'\x01'
    print('FPGA done after %d status reads.' % (status_reads))

def release_spi_flash_from_power_down():
    ser.write(b't')
    b = ser.read()
    assert b == b't'

def put_avr_into_passthrough_mode():
    ser.write(b'z')
    b = ser.read()
    print(repr(b))
    # TODO Not sure why this doesn't work; probably need a dealy
    assert b == b'z'
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

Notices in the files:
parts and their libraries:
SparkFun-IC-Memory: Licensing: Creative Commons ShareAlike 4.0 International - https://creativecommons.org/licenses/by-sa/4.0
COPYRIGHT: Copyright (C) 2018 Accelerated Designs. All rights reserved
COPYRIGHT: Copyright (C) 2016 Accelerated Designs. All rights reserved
